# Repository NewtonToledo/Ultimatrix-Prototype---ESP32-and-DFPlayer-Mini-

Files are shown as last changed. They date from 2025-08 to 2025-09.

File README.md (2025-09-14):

# Ultimatrix Prototype with ESP32
## Overview
The Ultimatrix Project is inspired by the iconic device featured in Ben 10 animated series. 
It recreates the aesthetic and interactive experience of the fictional watch by integrating microcontrollers, sound modules, and a custom 3D-printed case. 
Beyond its entertainment value, the project also has an educational purpose by incorporating features that support the teaching and practice of English vocabulary in a playful and engaging way. 
This dual approach positions the Ultimatrix as both a functional prototype for entertainment and a didactic tool for language learning.

<p align="center">
  
  <br>
  <em>Image 1. Final Prototype</em>
</p>

## Materials and Components  

The development of the project required a combination of electronic, mechanical, and structural elements. The following table summarizes the main products and materials used:  

| Component | Description |
|---|---|
| **Microcontroller (ESP32)** | Central unit that controls inputs, outputs, and system logic |
| **Push Buttons** | Allow user interaction, menu navigation, and activation |
| **OLED Display (SH1107)** | Visual interface for menus, text, and alien selection |
| **Potentiometer** | Dial construction and alien selection |
| **Speaker** | Generate sound feedback and transformation effects |
| **Sound Module (DFPlayer Mini)** | Generate sound feedback and transformation effects |
| **Powerbank** | Primary power source for the device |
| **3D-Printed Case** | Structural housing that protects and enhances aesthetics |
| **Passive Components** | Circuit stability, safety, and proper connections |

<p align="center">
  
  <br>
  <em>Image 2. Assembling the components</em>
</p>

## Operation modes explained
The Ultimatrix includes several interactive modes that enhance both entertainment and educational experiences; these modes can be selected by the assigned button:  

- **MP3 Player:**  
  When powered on, the system displays a music player with the tracks stored on the micro SD card. With the buttons we can change the volume or pause and play the song;
   with the dial it's possible to select a desired song.  

- **Ultimatrix startup:**  
  The display shows the Omnitrix icon with a specific audio, telling the user that has achieved the master control.

- **Alien Selection Mode:**  
  Users navigate through aliens on the OLED display using the dial with the potentiometer, accompanied by sound effects that resemble the original watch interface.
  There are two modes dedicated to the alien selection, the first one is the classic series menu, and the other one has the Alien Force menu.

- **English Learning Mode:**  
  The last 4 modes are dedicated to English learning through easy phrases, vowels, numbers, and colors.

## Video Demo  

<p align="center">
  <a href="https://www.youtube.com/watch?v=3azAWYxgHlA" target="_blank">
    Watch the Short
  </a>
  <br>
  <em>Demo of the Ultimatrix Project</em>
</p>

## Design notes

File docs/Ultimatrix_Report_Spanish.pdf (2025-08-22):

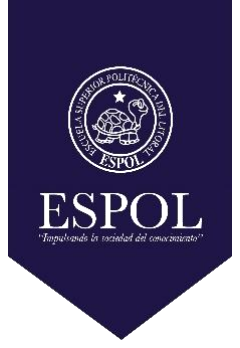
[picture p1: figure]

ESCUELA SUPERIOR POLITÉCNICA DEL LITORAL

FACULTAD DE INGENIERÍA MECÁNICA Y CIENCIAS DE LA PRODUCCIÓN

## PULSERA – OLED – DF PLAYER MINI

## SISTEMAS EMBEBIDOS

## Estudiantes: Eliezer Acebo Ronald Cordero Jaime Escala Newton Toledo Gabriel Reyes

08 – 2025

Descripción del prototipo

El prototipo realizo fue un modelo de Omnitrix (tipo de brazalete) simulando la función del programa de televisión para niños Ben 10. Este prototipo fue construido y programado mediante el sistema embebido llamado ESP32 como su microcontrolador central, además contiene cuatro diferentes modos que pueden cambiar entre ellos si se pulsa el botón indicado para esta función:

1) Modo Mp3: modo de que contiene 4 canciones que cambiaran por medio del scroll situado en el borde de la pantalla. Este funcionará mediante la implementación de un módulo DFPlayer Mini.
2) Modo Omnitrix: modo que permite visualizar la imagen principal que representa a la serie (logo del Omnitrix).
3) Modo Omnitrix (primera versión): modo que permite visualizar la primera versión de los alienígenas de Ben que van cambiando al ir utilizando el scroll. Cada alienígena emite un sonido al ir cambiando.
4) Modo Omnitrix (segunda versión): modo que permite visualizar la segunda versión de los alienígenas. Mientras van cambiando los alienígenas emiten un sonido para cada uno.

Adicionalmente, es importante mencionar que todas estas imágenes se visualizan debido al uso de una pantalla OLED (I2C) y el Omnitrix contiene tres botones más, uno para aumentar volumen, otro para reducirlo y finalmente uno que permite pausar.

Diseño 3D

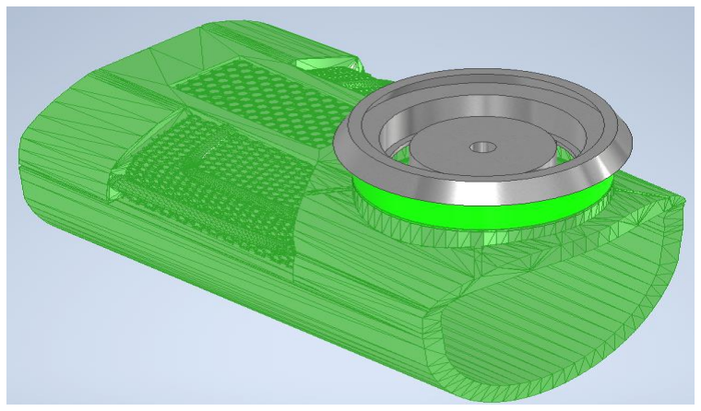
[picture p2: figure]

Figura 1 Omnitrix

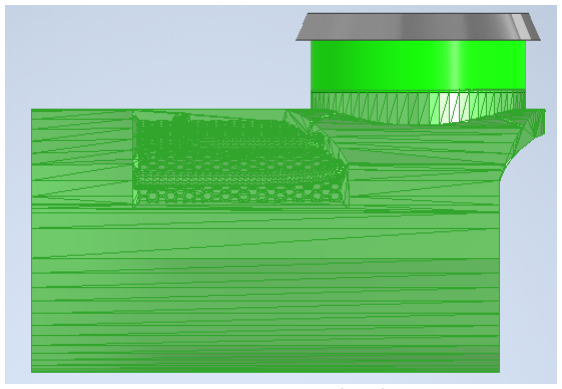
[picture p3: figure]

Figura 2 Omnitrix vista lateral

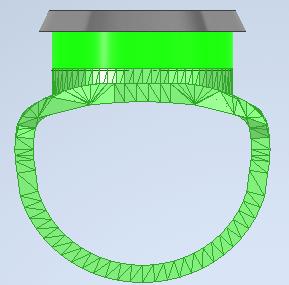
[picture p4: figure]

Figura 3 Omnitrix vista frontal

Conexiones realizadas

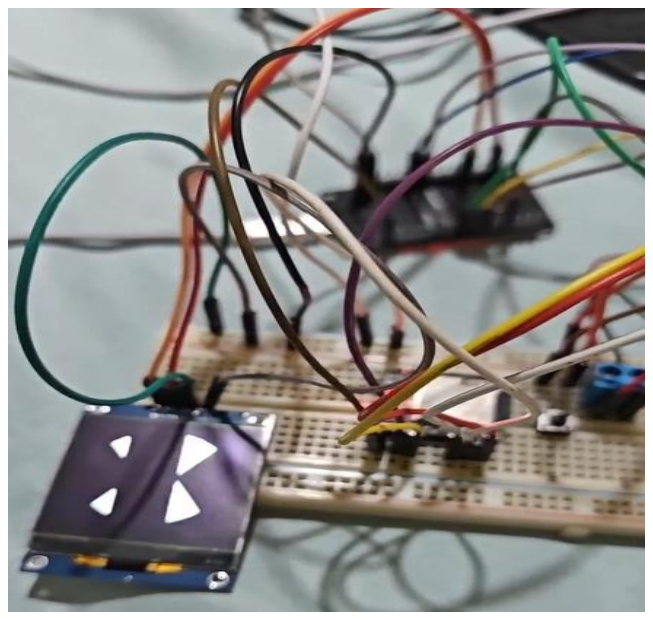
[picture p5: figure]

Figura 4 Conexiones en protoboard

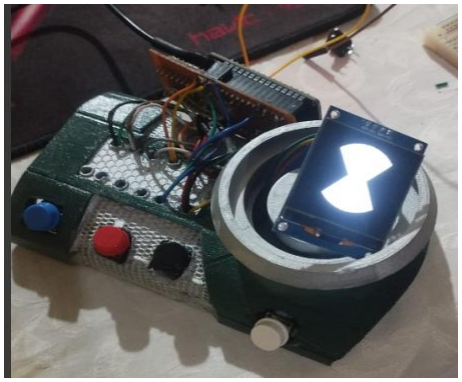
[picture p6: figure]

Figura 5 Conexiones Omnitrix

Video de YouTube

- https://www.youtube.com/watch?v=Kj00MawhlZA

Enlace a repositorio en GitHub

- https://github.com/NewtonToledo/Ultimatrix-Prototype---ESP32-and-DFPlayer-Mini-.git (https://github.com/NewtonToledo/Ultimatrix-Prototype---ESP32-and-DFPlayer-Mini-.git)

Aplicación

- Aplicaciones reales módulo DFPlayer Mini en sistemas embebidos:
- Sistemas de seguridad: el módulo suele ser utilizado en sistemas de seguridad para emitir alertas o mensajes de voz en caso de fallos en diferentes operaciones reales.
- Robótica: los módulos DFPlayer Mini suelen ser utilizados en robots armados para proyectos educativos o para simular movimientos humanos con sonidos reales.
- Museos: implementados para que cada exhibición contenga un emulador de sonidos que explique cada obra al recibir una señal por medio de un sensor que detecta personas.

Propuesta de sistema

- Propuesta: Se diseña un prototipo de Omnitrix controlado mediante un ESP32 como microcontrolador principal que permita emular por medio del software canciones mediante un módulo DFPlayer Mini y que se puedan visualizar imágenes utilizando una pantalla OLED (I2C).
- Diagrama esquemático:

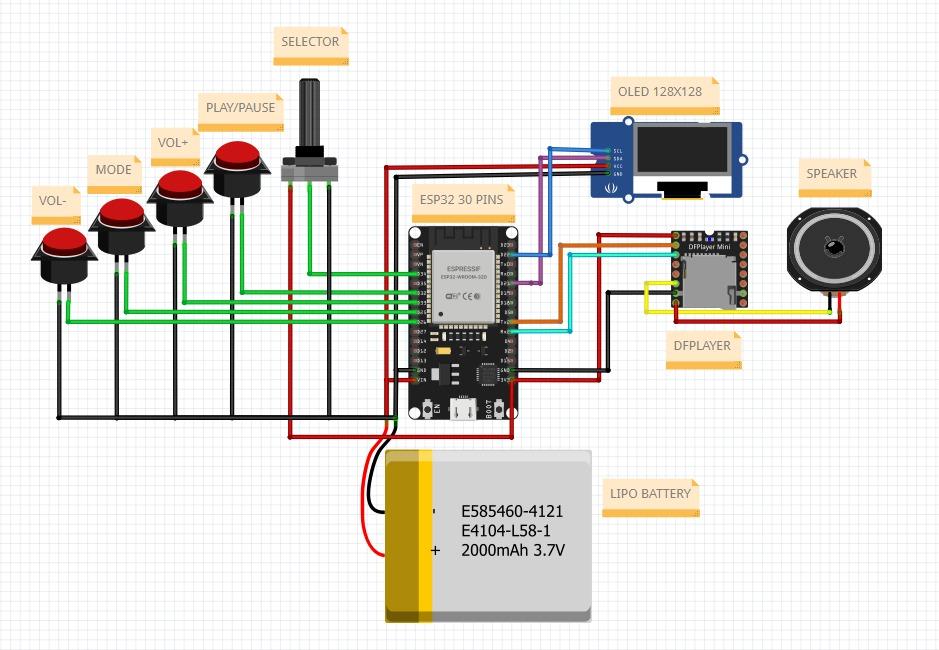
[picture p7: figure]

Figura 6 Diagrama esquemático Omnitrix

Análisis crítico

DFPlayer Mini
Ventajas | Limitaciones
Permite pausar, y ajustar volumen. | El firmware no es actualizable.
Lee archivos MP3 desde microSD liberando memoria y CPU. | Se limita el volumen máximo por medio del software porque puede dañar el altavoz.
Comunicación por UART o por pines de control directo. | El ruido de fondo es perceptible a volúmenes altos.

Conclusiones

- En conclusión, la integración del DFPlayer Mini permitió dotar al Omnitrix de audio autónomo a muy bajo costo y por lo tanto liberó al ESP32 para gestionar la pantalla y la lógica de modos sin sobrecarga. De este modo el sistema alcanzó varias horas de operación continua con la batería de 2000 mAh y además mantuvo un consumo moderado adecuado para uso portátil. En consecuencia se validó que un conjunto reducido de componentes es suficiente para ofrecer una experiencia multimedia completa.
- Además, la topología UART más I2C mantuvo un esquema eléctrico limpio y estable y asimismo facilitó la integración de los botones y el encoder para cambios de pista. En seguida la navegación secuencial de archivos permitió transiciones fluidas entre modos y por consiguiente reforzó la inmersión del usuario. En consecuencia el prototipo demostró potencial para kits educativos y exhibiciones interactivas.
- Finalmente, el DFPlayer presenta ligero ruido de fondo y reglas rígidas de nomenclatura y sin embargo los filtros de alimentación junto con una masa común mitigaron tales efectos. Por ende las limitaciones no comprometieron la meta de una experiencia multimedia inmersiva y asimismo probaron la viabilidad de escalar el proyecto. De esta forma se concluye que las precauciones de diseño superan con creces las desventajas inherentes del módulo.

Recomendaciones

- Es necesario colocar un condensador de al menos 470 µF muy próximo al VCC del DFPlayer y además mantener cortas las pistas de potencia y aislar la tierra analógica del audio. De este modo se evitan reinicios del ESP32 y se reducen chasquidos audibles y por consiguiente se incrementa la robustez del prototipo cuando funciona solo con la batería. Finalmente conviene revisar el cableado ante cada ensamble para asegurar la integridad de la masa común.
- Es importante que el volumen máximo se limite por software y se documente rigurosamente la convención de nombres numéricos dentro de carpetas. Asimismo, resulta conveniente validar cada tarjeta SD antes de la producción y verificar la versión de firmware del DFPlayer. Con ello se protege el altavoz y la audición del usuario y además se garantiza la compatibilidad del sistema en futuras iteraciones.

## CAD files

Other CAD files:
Ultimatrix Model - Inventor files/Scroll_nuevo.ipt
Ultimatrix Model - Inventor files/back-01.ipt
Ultimatrix Model - Inventor files/top_.ipt

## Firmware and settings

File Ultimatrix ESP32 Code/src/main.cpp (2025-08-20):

#include <Arduino.h>
#include <HardwareSerial.h>
#include <DFRobotDFPlayerMini.h>
#include <freertos/FreeRTOS.h>
#include <freertos/semphr.h>
#include <freertos/task.h>
#include <Wire.h>
#include <Adafruit_GFX.h>
#include <Adafruit_SH110X.h>
#include "image128.h"
#include "esp_system.h"
#include "WiFi.h"
#include "esp_bt.h"
#include "soc/rtc.h"

// ——— Pines y configuración ———
#define POT_PIN         34
#define BTN_PLAY_PIN    32
#define BTN_VOLUP_PIN   33
#define BTN_VOLDN_PIN   27   // <- volumen en 27 como pediste
#define BTN_MODE_PIN    25
#define RX2_PIN         16
#define TX2_PIN         17
#define TOTAL_TRACKS    8

// nombres de canciones
const char* fileNames[TOTAL_TRACKS+1] = {
  "", "Ben 10 Intro", "Bring me to life", "Faded", "Force", "Power Rangers", "Enemy", "DBZ Opening", "Legends Never Die"
};
// duraciones en segundos
const uint16_t trackDurations[TOTAL_TRACKS+1] = {
  0, 61, 244, 212, 240, 241, 187, 111, 235
};

// ——— Modo 4: Frases en inglés ———
#define NUM_FRASES 10
const char* frasesEN[NUM_FRASES] = {
  "Hello", 
  "Excuse me", "I'm sorry", "Please", "Thank you",
  "Again", "Good job", "Bye", "Help me!", "Hero Time!"
};
const char* frasesES[NUM_FRASES] = {
  "\"Hola\"", 
  "\"Con permiso\"", "\"Lo siento\"", "\"Por favor\"", "\"Gracias\"",
  "\"Otra vez\"", "\"Buen trabajo\"", "\"Adios\"", "\"Ayudame!\"", "\"Hora de ser heroe!\""
};
const uint8_t fraseTracks[NUM_FRASES] = { 12,13,14,15,16,17,18,19,20,21 };
volatile uint8_t currentFraseIndex = 0;

// ——— Modo 5: Vocales ———
#define NUM_VOCALES 5
const char* vocales[NUM_VOCALES] = { "a","e","i","o","u" };
const uint8_t vocalTracks[NUM_VOCALES] = { 22,23,24,25,26 };
volatile uint8_t currentVocalIndex = 0;

// ——— Modo 6: Números (1–10) ———
#define NUM_NUMS 10
const char* numerosEN[NUM_NUMS] = { "One","Two","Three","Four","Five","Six","Seven","Eight","Nine","Ten" };
const uint8_t numeroTracks[NUM_NUMS] = { 27,28,29,30,31,32,33,34,35,36 };
volatile uint8_t currentNumeroIndex = 0; // 0..9 → 1..10

// ——— Modo 7: Colores ———
#define NUM_COLORES 10
const char* coloresEN[NUM_COLORES] = {
  "Red","Blue","Yellow","Green","Orange","Purple","Brown","Pink","White","Black"
};
const char* coloresES[NUM_COLORES] = {
  "\"Rojo\"","\"Azul\"","\"Amarillo\"","\"Verde\"","\"Naranja\"","\"Morado\"","\"Cafe\"","\"Rosa\"","\"Blanco\"","\"Negro\""
};
const uint8_t colorTracks[NUM_COLORES] = { 37,38,39,40,41,42,43,44,45,46 };
volatile uint8_t currentColorIndex = 0;

// pantalla SH1107 I2C
#define SCREEN_WIDTH   128
#define SCREEN_HEIGHT  128
#define OLED_RESET     -1
#define I2C_ADDRESS    0x3C
Adafruit_SH1107 display(SCREEN_WIDTH, SCREEN_HEIGHT, &Wire, OLED_RESET);

// DFPlayer y sincronización
HardwareSerial       dfSerial(2);
DFRobotDFPlayerMini  player;
SemaphoreHandle_t    playerMutex;

// ——— Estado MP3 ———
volatile int     currentTrack    = 1;   // 1..TOTAL_TRACKS
volatile bool    isPlaying       = false;
uint32_t         trackStartTime  = 0;
uint32_t         trackDurationMs = 0;
bool             pauseState      = false;
uint32_t         pauseStartTime  = 0;

// ——— Icono de volumen ———
volatile bool    volFlag      = false;
volatile int     volIconType  = 0;    // 1=+Vol, 2=-Vol
uint32_t         volTime      = 0;

// ——— Modos ———
// 0 = reproductor MP3 (pot selecciona pista)
// 1 = icono omnitrix (reproduce sonido al entrar)
// 2 = grupo aliens M2 (pot cambia imagen + FX al girar)
// 3 = grupo aliens M3 (pot cambia imagen + FX al girar)
// 4 = frases EN/ES (pot selecciona frase)
// 5 = vocales (pot selecciona vocal)
// 6 = números (pot selecciona número)
// 7 = colores EN/ES (pot selecciona color)
volatile uint8_t mode = 0;

#define MODES_COUNT        8
#define MODE1_SOUND_TRACK  11

// ——— Imágenes ———
#define NUM_IMAGES 10
extern const uint8_t* const imagenesModo2[NUM_IMAGES];
extern const uint8_t* const imagenesModo3[NUM_IMAGES];
volatile uint8_t currentImageIndex = 0;

// ——— Estados de sincronización por modo (reemplazan statics) ———
volatile int8_t lastTrackIdx   = -1; // mode 0 (0..TOTAL_TRACKS-1)
volatile int8_t lastImageIdx2  = -1; // mode 2
volatile int8_t lastImageIdx3  = -1; // mode 3
volatile int8_t lastFraseIdx   = -1; // mode 4
volatile int8_t lastVocalIdx   = -1; // mode 5
volatile int8_t lastNumeroIdx  = -1; // mode 6
volatile int8_t lastColorIdx   = -1; // mode 7

// Helper de mapeo 0..4095 → 0..count-1
static inline uint8_t mapPotToIndex(int raw, int count) {
  if (raw < 0) raw = 0;
  if (raw > 4095) raw = 4095;
  int idx = (int)((uint32_t)raw * (uint32_t)count / 4096U);
  if (idx >= count) idx = count - 1;
  return (uint8_t)idx;
}

// ——— Prototipos ———
void nextTrackAuto();
void taskPot(void*);
void taskButtons(void*);
void taskDisplay(void*);

void setup() {
  setCpuFrequencyMhz(80);         // mantener 80 MHz
  WiFi.mode(WIFI_OFF);
  btStop();

  // DFPlayer
  dfSerial.begin(9600, SERIAL_8N1, RX2_PIN, TX2_PIN);
  while (!player.begin(dfSerial)) { delay(200); }
  player.volume(20);
  player.play(currentTrack);
  isPlaying       = true;
  trackStartTime  = millis();
  trackDurationMs = trackDurations[currentTrack] * 1000UL;

  // potenciómetro
  analogReadResolution(12);
  analogSetPinAttenuation(POT_PIN, ADC_11db);
  pinMode(POT_PIN, INPUT);

  // botones
  pinMode(BTN_PLAY_PIN, INPUT_PULLUP);
  pinMode(BTN_VOLUP_PIN, INPUT_PULLUP);
  pinMode(BTN_VOLDN_PIN, INPUT_PULLUP);
  pinMode(BTN_MODE_PIN, INPUT_PULLUP);

  // pantalla
  Wire.begin(21, 22);
  if (!display.begin(I2C_ADDRESS)) { while (true); }
  display.clearDisplay();
  display.display();

  // FreeRTOS
  playerMutex = xSemaphoreCreateMutex();
  xTaskCreatePinnedToCore(taskPot,      "POT", 4096, NULL, 2, NULL, 1);
  xTaskCreatePinnedToCore(taskButtons,  "BTN", 2048, NULL, 2, NULL, 1);
  xTaskCreatePinnedToCore(taskDisplay,  "DSP", 2048, NULL, 1, NULL, 1);
}

void loop() {
  vTaskDelay(portMAX_DELAY);
}

void nextTrackAuto() {
  xSemaphoreTake(playerMutex, portMAX_DELAY);
    currentTrack    = (currentTrack < TOTAL_TRACKS ? currentTrack + 1 : 1);
    player.play(currentTrack);
    isPlaying       = true;
    pauseState      = false;
    trackStartTime  = millis();
    trackDurationMs = trackDurations[currentTrack] * 1000UL;
    lastTrackIdx    = currentTrack - 1; // mantener sincronía con pot
  xSemaphoreGive(playerMutex);
}

// ——— Potenciómetro: controla modos 0,2,3,4,5,6,7 ———
void taskPot(void *pv) {
  int lastRaw = -1;
  for (;;) {
    int raw = analogRead(POT_PIN);

    if (abs(raw - lastRaw) > 60) {   // pequeña histéresis anti-ruido
      lastRaw = raw;

      // Modo 0: selector de pistas 1..TOTAL_TRACKS
      if (mode == 0) {
        uint8_t idx0 = mapPotToIndex(raw, TOTAL_TRACKS); // 0..TOTAL_TRACKS-1
        if (idx0 != lastTrackIdx) {
          uint8_t track = idx0 + 1;
          xSemaphoreTake(playerMutex, pdMS_TO_TICKS(80));
            player.play(track);
            currentTrack    = track;
            isPlaying       = true;
            pauseState      = false;
            trackStartTime  = millis();
            trackDurationMs = trackDurations[currentTrack] * 1000UL;
          xSemaphoreGive(playerMutex);
          lastTrackIdx = idx0;
        }
      }
      // Modo 2: imágenes grupo 2 + FX al cambiar
      else if (mode == 2) {
        uint8_t idx = mapPotToIndex(raw, NUM_IMAGES);
        if (idx != lastImageIdx2) {
          xSemaphoreTake(playerMutex, pdMS_TO_TICKS(80));
            player.play(10);   // efecto cambio
          xSemaphoreGive(playerMutex);
          currentImageIndex = idx;
          lastImageIdx2     = idx;
        }
      }
      // Modo 3: imágenes grupo 3 + FX al cambiar
      else if (mode == 3) {
        uint8_t idx = mapPotToIndex(raw, NUM_IMAGES);
        if (idx != lastImageIdx3) {
          xSemaphoreTake(playerMutex, pdMS_TO_TICKS(80));
            player.play(10);   // efecto cambio
          xSemaphoreGive(playerMutex);
          currentImageIndex = idx;
          lastImageIdx3     = idx;
        }
      }
      // Modo 4: frases EN/ES
      else if (mode == 4) {
        uint8_t idx = mapPotToIndex(raw, NUM_FRASES);
        if (idx != lastFraseIdx) {
          xSemaphoreTake(playerMutex, pdMS_TO_TICKS(80));
            player.play(fraseTracks[idx]);
            isPlaying = true;
          xSemaphoreGive(playerMutex);
          currentFraseIndex = idx;
          lastFraseIdx      = idx;
        }
      }
      // Modo 5: vocales
      else if (mode == 5) {
        uint8_t idx = mapPotToIndex(raw, NUM_VOCALES);
        if (idx != lastVocalIdx) {
          xSemaphoreTake(playerMutex, pdMS_TO_TICKS(80));
            player.play(vocalTracks[idx]);
            isPlaying = true;
          xSemaphoreGive(playerMutex);
          currentVocalIndex = idx;
          lastVocalIdx      = idx;
        }
      }
      // Modo 6: números
      else if (mode == 6) {
        uint8_t idx = mapPotToIndex(raw, NUM_NUMS);
        if (idx != lastNumeroIdx) {
          xSemaphoreTake(playerMutex, pdMS_TO_TICKS(80));
            player.play(numeroTracks[idx]);
            isPlaying = true;
          xSemaphoreGive(playerMutex);
          currentNumeroIndex = idx;
          lastNumeroIdx      = idx;
        }
      }
      // Modo 7: colores
      else if (mode == 7) {
        uint8_t idx = mapPotToIndex(raw, NUM_COLORES);
        if (idx != lastColorIdx) {
          xSemaphoreTake(playerMutex, pdMS_TO_TICKS(80));
            player.play(colorTracks[idx]);
            isPlaying = true;
          xSemaphoreGive(playerMutex);
          currentColorIndex = idx;
          lastColorIdx      = idx;
        }
      }
    }

    vTaskDelay(pdMS_TO_TICKS(40)); // latencia baja sin saturar
  }
}

// ——— Botones ———
void taskButtons(void *pv) {
  bool lastP = HIGH, lastU = HIGH, lastD = HIGH, lastM = HIGH;
  for (;;) {
    bool m = digitalRead(BTN_MODE_PIN);
    if (m == LOW && lastM == HIGH) {
      // cambiar de modo
      uint8_t newMode = (mode + 1) % MODES_COUNT;

      xSemaphoreTake(playerMutex, portMAX_DELAY);
        mode = newMode;

        // Lee pot “ya” para entrar sincronizado en cada modo
        int rawNow = analogRead(POT_PIN);

        if      (mode == 0) {
          uint8_t idx0  = mapPotToIndex(rawNow, TOTAL_TRACKS);
          uint8_t track = idx0 + 1;
          currentTrack  = track;
          lastTrackIdx  = idx0;
          player.play(track);
          isPlaying = true;
          pauseState = false;
          trackStartTime  = millis();
          trackDurationMs = trackDurations[currentTrack] * 1000UL;
        }
        else if (mode == 1) {
          player.play(MODE1_SOUND_TRACK);
          isPlaying = true;
        }
        else if (mode == 2) {
          uint8_t idx = mapPotToIndex(rawNow, NUM_IMAGES);
          currentImageIndex = idx;
          lastImageIdx2     = idx;
          player.pause();
          player.play(9);   // sonido de entrada modo 2
          isPlaying = false;
        }
        else if (mode == 3) {
          uint8_t idx = mapPotToIndex(rawNow, NUM_IMAGES);
          currentImageIndex = idx;
          lastImageIdx3     = idx;
          player.pause();
          player.play(9);   // sonido de entrada modo 3
          isPlaying = false;
        }
        else if (mode == 4) {
          uint8_t idx = mapPotToIndex(rawNow, NUM_FRASES);
          currentFraseIndex = idx;
          lastFraseIdx      = idx;
          player.play(fraseTracks[idx]);
          isPlaying = true;
        }
        else if (mode == 5) {
          uint8_t idx = mapPotToIndex(rawNow, NUM_VOCALES);
          currentVocalIndex = idx;
          lastVocalIdx      = idx;
          player.play(vocalTracks[idx]);
          isPlaying = true;
        }
        else if (mode == 6) {
          uint8_t idx = mapPotToIndex(rawNow, NUM_NUMS);
          currentNumeroIndex = idx;
          lastNumeroIdx      = idx;
          player.play(numeroTracks[idx]);
          isPlaying = true;
        }
        else if (mode == 7) {
          uint8_t idx = mapPotToIndex(rawNow, NUM_COLORES);
          currentColorIndex = idx;
          lastColorIdx      = idx;
          player.play(colorTracks[idx]);
          isPlaying = true;
        }
      xSemaphoreGive(playerMutex);
    }
    lastM = m;

    // Controles del reproductor (sólo en modo 0)
    if (mode == 0) {
      // play/pause
      bool p = digitalRead(BTN_PLAY_PIN);
      if (p == LOW && lastP == HIGH) {
        xSemaphoreTake(playerMutex, portMAX_DELAY);
          if (isPlaying) {
            player.pause();
            isPlaying      = false;
            pauseState     = true;
            pauseStartTime = millis();
          } else {
            player.start();
            trackStartTime += millis() - pauseStartTime;
            isPlaying      = true;
            pauseState     = false;
          }
        xSemaphoreGive(playerMutex);
      }
      lastP = p;

      // volumen +
      bool u = digitalRead(BTN_VOLUP_PIN);
      if (u == LOW && lastU == HIGH) {
        xSemaphoreTake(playerMutex, portMAX_DELAY);
          player.volumeUp();
          volFlag     = true;
          volIconType = 1;
          volTime     = millis();
        xSemaphoreGive(playerMutex);
      }
      lastU = u;

      // volumen –
      bool d = digitalRead(BTN_VOLDN_PIN);
      if (d == LOW && lastD == HIGH) {
        xSemaphoreTake(playerMutex, portMAX_DELAY);
          player.volumeDown();
          volFlag     = true;
          volIconType = 2;
          volTime     = millis();
        xSemaphoreGive(playerMutex);
      }
      lastD = d;
    }

    vTaskDelay(pdMS_TO_TICKS(30));
  }
}

// ——— Display ———
void taskDisplay(void *pv) {
  const int refreshMs = 120;
  static uint32_t lastRefresh = 0;
  static int16_t  fnameX     = -100;
  static bool     fnameDirR  = true;
  static uint32_t lastMove   = 0;
  char buf[24];

  for (;;) {
    uint32_t now = millis();
    if (now - lastRefresh < (uint32_t)refreshMs) {
      vTaskDelay(pdMS_TO_TICKS(5));
      continue;
    }
    lastRefresh = now;

    display.clearDisplay();
    display.setTextColor(SH110X_WHITE);
    display.setTextWrap(false);

    if (mode == 0) {
      display.setTextSize(1);

      // cronómetro & auto-next
      uint32_t elapsed = pauseState
        ? (pauseStartTime - trackStartTime)
        : (now - trackStartTime);
      if (elapsed > trackDurationMs) elapsed = trackDurationMs;
      if (elapsed >= trackDurationMs) {
        // Al terminar la canción, tomar lectura del pot y reproducir la pista correspondiente
        int raw = analogRead(POT_PIN);
        int next = raw * TOTAL_TRACKS / 4096 + 1;
        next = constrain(next, 1, TOTAL_TRACKS);

        xSemaphoreTake(playerMutex, portMAX_DELAY);
          currentTrack    = next;
          player.play(currentTrack);
          isPlaying       = true;
          pauseState      = false;
          trackStartTime  = millis();
          trackDurationMs = trackDurations[currentTrack] * 1000UL;
        xSemaphoreGive(playerMutex);

        elapsed = 0;
      }


      // 1) Track #
      snprintf(buf, sizeof(buf), "Track %d", currentTrack);
      int tw = strlen(buf) * 6;
      display.setCursor(14 + (100 - tw)/2, 14);
      display.print(buf);

      // 2) Marquesina filename
      int fw      = strlen(fileNames[currentTrack]) * 6;
      int16_t lb  = 14, rb = 14 + 100 - fw;
      if (now - lastMove >= 120) {
        lastMove = now;
        if (fnameDirR) { if (++fnameX >= rb) fnameDirR = false; }
        else            { if (--fnameX <= lb) fnameDirR = true; }
      }
      display.setCursor(fnameX, 26);
      display.print(fileNames[currentTrack]);

      // 3) Cronómetro
      uint16_t m = elapsed / 60000;
      uint16_t s = (elapsed / 1000) % 60;
      snprintf(buf, sizeof(buf), "%02u:%02u", m, s);
      tw = strlen(buf) * 6;
      display.setCursor(14 + (100 - tw)/2, 38);
      display.print(buf);

      // 4) Icono ▶ / ⏸
      int cx = 64, cy = 80;
      if (isPlaying) {
        display.fillRect(cx-6, cy-6, 4, 12, SH110X_WHITE);
        display.fillRect(cx+2, cy-6, 4, 12, SH110X_WHITE);
      } else {
        display.fillTriangle(cx-6, cy-6, cx-6, cy+6, cx+6, cy, SH110X_WHITE);
      }

      // 5) Barra progreso
      int barY = cy + 12;
      display.drawRect(14, barY, 100, 3, SH110X_WHITE);
      uint32_t w = (uint64_t)elapsed * 100 / trackDurationMs;
      if (w > 0) display.fillRect(14, barY, w, 3, SH110X_WHITE);

      // 6) +Vol / -Vol
      if (volFlag && now - volTime < 1000) {
        const char* vstr = (volIconType == 1 ? "+Vol" : "-Vol");
        tw = strlen(vstr) * 6;
        display.setCursor(14 + (100 - tw)/2, barY + 10);
        display.print(vstr);
      } else {
        volFlag = false;
      }
    }
    else if (mode == 1) {
      display.drawBitmap(0, 0, omnitrix, SCREEN_WIDTH, SCREEN_HEIGHT, SH110X_WHITE);
    }
    else if (mode == 2) {
      display.drawBitmap(0, 0, imagenesModo2[currentImageIndex], SCREEN_WIDTH, SCREEN_HEIGHT, SH110X_WHITE);
    }
    else if (mode == 3) {
      display.drawBitmap(0, 0, imagenesModo3[currentImageIndex], SCREEN_WIDTH, SCREEN_HEIGHT, SH110X_WHITE);
    }
    else if (mode == 4) {
      // Frase EN (size 2)
      display.setTextSize(2);
      const char* en = frasesEN[currentFraseIndex];
      int enW = strlen(en) * 6 * 2;
      int enX = (SCREEN_WIDTH - enW) / 2; if (enX < 0) enX = 0;
      display.setCursor(enX, 28);
      display.print(en);

      // Traducción ES (size 1)
      display.setTextSize(1);
      const char* es = frasesES[currentFraseIndex];
      int esW = strlen(es) * 6;
      int esX = (SCREEN_WIDTH - esW) / 2; if (esX < 0) esX = 0;
      display.setCursor(esX, 54);
      display.print(es);

      // Indicador
      char ibuf[12];
      snprintf(ibuf, sizeof(ibuf), "%u/%u", currentFraseIndex + 1, NUM_FRASES);
      int tw = strlen(ibuf) * 6;
      display.setCursor((SCREEN_WIDTH - tw)/2, 72);
      display.print(ibuf);
    }
    else if (mode == 5) {
      // Vocal grande (size 4)
      display.setTextSize(4);
      const char* v = vocales[currentVocalIndex];
      int vW = strlen(v) * 6 * 4;
      int vX = (SCREEN_WIDTH - vW) / 2; if (vX < 0) vX = 0;
      display.setCursor(vX, 36);
      display.print(v);

      display.setTextSize(1);
      snprintf(buf, sizeof(buf), "%u/%u", currentVocalIndex + 1, NUM_VOCALES);
      int tw = strlen(buf) * 6;
      display.setCursor((SCREEN_WIDTH - tw)/2, 86);
      display.print(buf);
    }
    else if (mode == 6) {
      // Número (size 3)
      display.setTextSize(3);
      char nbuf[3];
      uint8_t n = currentNumeroIndex + 1; // 1..10
      if (n == 10) { nbuf[0] = '1'; nbuf[1] = '0'; nbuf[2] = '\0'; }
      else { nbuf[0] = '0' + n; nbuf[1] = '\0'; }
      int nW = strlen(nbuf) * 6 * 3;
      int nX = (SCREEN_WIDTH - nW) / 2; if (nX < 0) nX = 0;
      display.setCursor(nX, 24);
      display.print(nbuf);

      // Palabra en inglés entre comillas (size 1)
      display.setTextSize(1);
      snprintf(buf, sizeof(buf), "\"%s\"", numerosEN[currentNumeroIndex]);
      int w2 = strlen(buf) * 6;
      int x2 = (SCREEN_WIDTH - w2) / 2; if (x2 < 0) x2 = 0;
      display.setCursor(x2, 64);
      display.print(buf);

      // Indicador
      char ibuf[12];
      snprintf(ibuf, sizeof(ibuf), "%u/%u", currentNumeroIndex + 1, NUM_NUMS);
      int tw = strlen(ibuf) * 6;
      display.setCursor((SCREEN_WIDTH - tw)/2, 84);
      display.print(ibuf);
    }
    else if (mode == 7) {
      // Color EN (size 2) + ES (size 1), como modo 4
      display.setTextSize(2);
      const char* cen = coloresEN[currentColorIndex];
      int enW = strlen(cen) * 6 * 2;
      int enX = (SCREEN_WIDTH - enW) / 2; if (enX < 0) enX = 0;
      display.setCursor(enX, 28);
      display.print(cen);

      display.setTextSize(1);
      const char* ces = coloresES[currentColorIndex];
      int esW = strlen(ces) * 6;
      int esX = (SCREEN_WIDTH - esW) / 2; if (esX < 0) esX = 0;
      display.setCursor(esX, 54);
      display.print(ces);

      char ibuf[12];
      snprintf(ibuf, sizeof(ibuf), "%u/%u", currentColorIndex + 1, NUM_COLORES);
      int tw = strlen(ibuf) * 6;
      display.setCursor((SCREEN_WIDTH - tw)/2, 72);
      display.print(ibuf);
    }

    display.display();
  }
}

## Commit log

2025-08-07 Add files via upload
    Archivos .cpp y .h añadidos desde proyecto de PlatformIO
2025-08-20 Inventor files added
    [Scroll_nuevo.ipt, back-01.ipt, top_.ipt]
2025-08-22 Documentation and backing tracks added
    [Ultimatrix_fritzing_design.fzz]
